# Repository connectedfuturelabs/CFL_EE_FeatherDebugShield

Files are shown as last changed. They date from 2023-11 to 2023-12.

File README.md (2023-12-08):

# Description
- This is a SWD breakout shield for the Feather M0 and a JTAG breakout shield for Feather ESP32.
- The Feather M0 has a provision for SWD debugging which requires soldering leads to the SWD pads on the bottom on the Feather M0. We made this shield so that we can debug a Feather M0 without having to solder leads. Instead, we use pogo pins to create the contact when the feather M0 is stacked on this shield.
- The Feather ESP32 can be debugged using the JTAG interface. This shield has a provision for debugging with ESP32 using solder bridges to create the necessary connections. **This configuration has not been tested.**
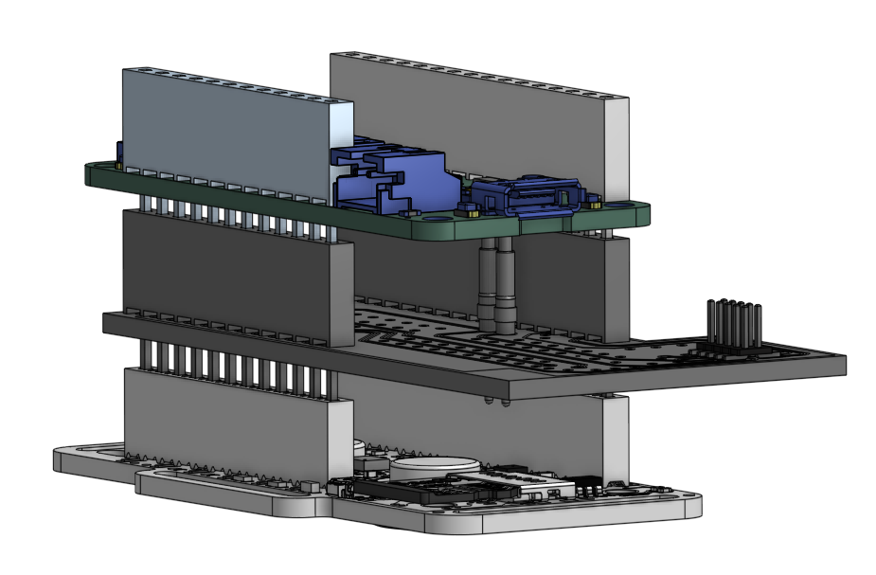
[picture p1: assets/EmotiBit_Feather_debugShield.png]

## Debug shield
**Note that this is a bare bones board (which is why the SM and silk screen are missing)**

| stage | how it looks |
|---|---|
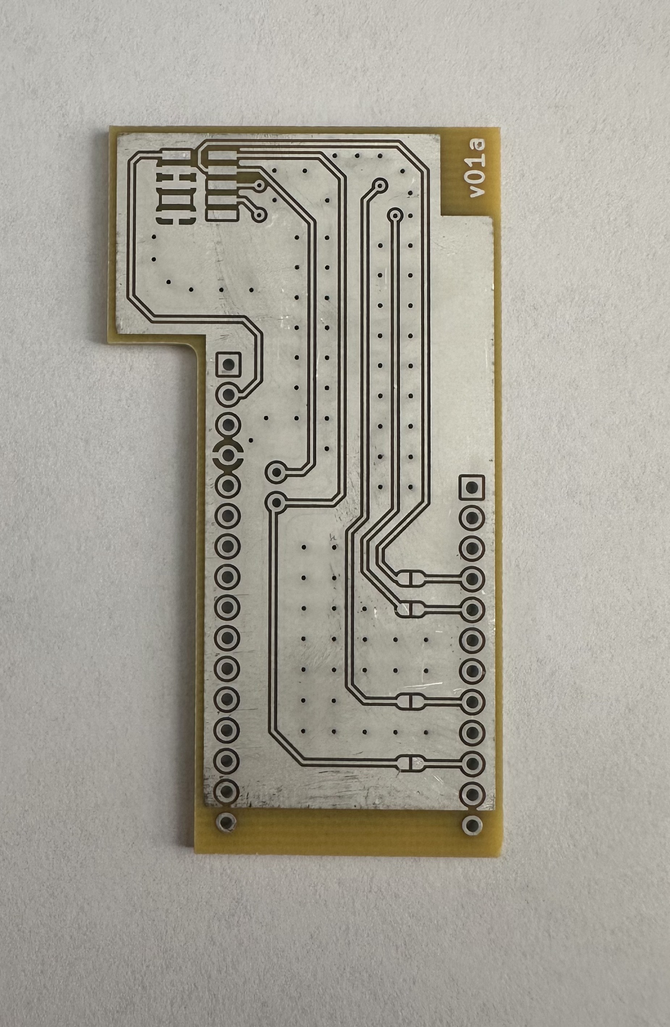
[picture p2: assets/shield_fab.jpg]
| After fabrication |  |
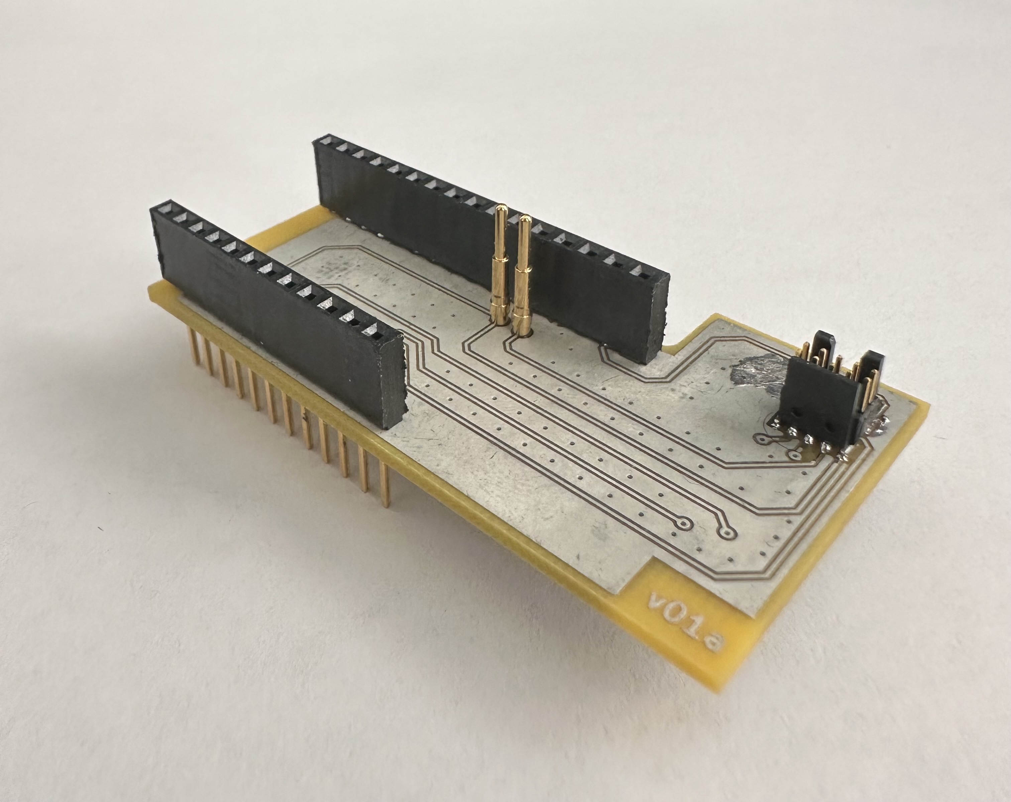
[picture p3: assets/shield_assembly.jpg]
| After Assembly |  |
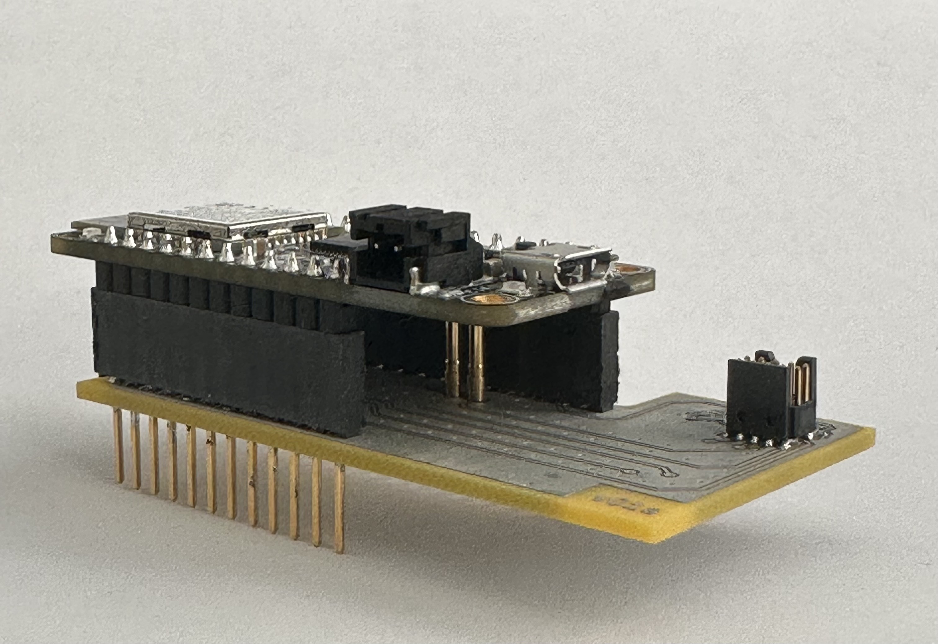
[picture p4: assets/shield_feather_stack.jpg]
| Stacked with a Feather |  |
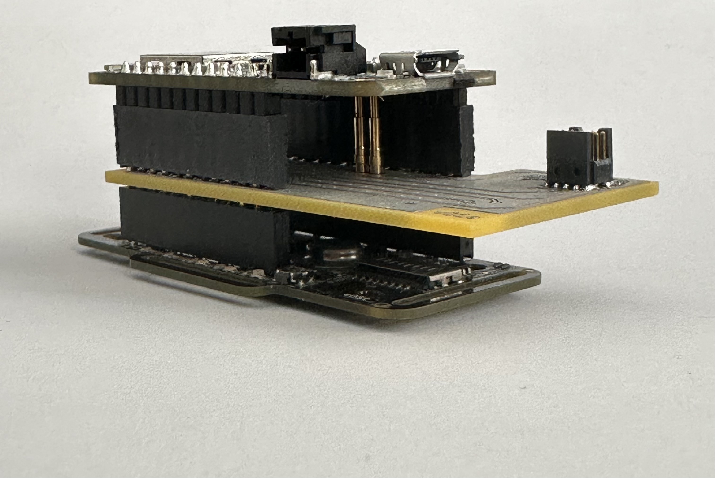
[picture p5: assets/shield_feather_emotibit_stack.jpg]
| Stacked with Feather and [EmotiBit](https://www.emotibit.com/) |  |

# Using this repository
- The latest release contains all files required for creating the board.
- To fabricate this board
  - Download the `.zip` from the release page.
  - The files needed for manufacturing are in the `Gerbers` folder.
  - Just upload the gerber design files on a manufacturer's website and choose other board specifications.
  - We used [`4PCB`](https://www.4pcb.com/pcb-prototype-2-4-layer-boards-specials.html) as our manufacturer.
  - The `_bom.csv` file contains the parts needed for assembly. You can directly upload the bom file into the digikey portal to get the required parts for assembly.
- Once the shield is fabbed and stacked, you can use the [10 pin JTAG conector cable](https://www.digikey.com/en/products/detail/olimex-ltd/ARM-JTAG-20-10/3471401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) to connecto to a [J-Link debugger](https://www.segger.com/products/debug-probes/j-link/).

## Assembly notes
- It is important to line up the pogo pins vertically to ensure there is a contact with the pads on the Feather. The following sequence helps with the allignment:
  - solder the 12 and 16 pin connector.
  - place the pogo pins in the correct position
  - stack the Feather on the shield.
  - then align the pogo pins with a pair of tweezers to ensure contact.
  - solder the pins in place
- We used stacking headers because we intend to use this as a triple stack with EmotiBit, but if you are only interested in debugging the Feather, then you can use normal female socket for the connector. 

# Additional Notes
- The design was created in Kicad 7.
- If you want to build on top of this design, please feel free to fork the repository and make the rewuired changes! you will need to download Kicad v7+ to work with the design files.

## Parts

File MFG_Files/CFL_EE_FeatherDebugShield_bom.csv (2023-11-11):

Component | Description | Part | References | Value | Footprint | Quantity Per PCB | Datasheet | Config | Land Pattern | MPN | Manufacturer | Max height | Mounting Type | Supplier 1 | Supplier 1 Link | Supplier 1 Part Number
1 | Generic connector, single row, 01x12, script generated (kicad-library-utils/schlib/autogen/connector/) | Conn_01x12 | J1 | Conn_01x12 | PinSocket_1x12_P2.54mm_Vertical | 1 | https://suddendocs.samtec.com/catalog_english/ssq_th.pdf |  | https://suddendocs.samtec.com/prints/ssq-1xx-xx-xx-x-xx-xxx-xx-xx.pdf | SSQ-112-03-G-S | Samtec Inc. | 8.61mm | Through hole | Digikey | https://www.digikey.com/en/products/detail/samtec-inc/SSQ-112-03-G-S/1111549 | SAM1198-12-ND
2 | Generic connector, single row, 01x16, script generated (kicad-library-utils/schlib/autogen/connector/) | Conn_01x16 | J2 | Conn_01x16 | PinSocket_1x16_P2.54mm_Vertical | 1 | https://suddendocs.samtec.com/catalog_english/ssq_th.pdf |  | https://suddendocs.samtec.com/prints/ssq-1xx-xx-xx-x-xx-xxx-xx-xx.pdf | SSQ-116-03-G-S | Samtec Inc. | 8.61mm | Through Hole | Digikey | https://www.digikey.com/en/products/detail/samtec-inc/SSQ-116-03-G-S/1111545 | SAM1198-16-ND
3 | Cortex Debug Connector, standard ARM Cortex-M SWD and JTAG interface | Conn_ARM_JTAG_SWD_10 | J4 | Conn_ARM_JTAG_SWD_10 | SAMTEC_FTSH-105-01-F-DV-K-TR | 1 | http://infocenter.arm.com/help/topic/com.arm.doc.ddi0314h/DDI0314H_coresight_components_trm.pdf |  | https://suddendocs.samtec.com/prints/ftsh-1xx-xx-xxx-dv-xxx-footprint.pdf | FTSH-105-01-F-DV-K-P | Samtec Inc. |  | SMD | Digikey | https://www.digikey.com/en/products/detail/samtec-inc./FTSH-105-01-F-DV-K-P/2649976 | SAM8797-ND
4 | CONTACT SPRING LOADED T/H GOLD | CONN_PROBE_SPRING_01X01_TH | J6 | SWCLK | CONN_PROBE_SPRING_01X01_C150H75 | 1 | https://www.mill-max.com/catalog/download/2020-03%3A025M.pdf |  | DNF | 0929-7-15-20-75-14-11-0 | Mill-Max Manufacturing Corp. | 12.2mm | Sureface Mount | DigiKey | https://www.digikey.com/en/products/detail/mill-max-manufacturing-corp/0929-7-15-20-75-14-11-0/5722643 | ED1420-ND
5 | CONTACT SPRING LOADED T/H GOLD | CONN_PROBE_SPRING_01X01_TH | J5 | SWDIO | CONN_PROBE_SPRING_01X01_C150H75 | 1 | https://www.mill-max.com/catalog/download/2020-03%3A025M.pdf |  | DNF | 0929-7-15-20-75-14-11-0 | Mill-Max Manufacturing Corp. | 12.2mm | Sureface Mount | DigiKey | https://www.digikey.com/en/products/detail/mill-max-manufacturing-corp/0929-7-15-20-75-14-11-0/5722643 | ED1420-ND
Component Groups: | 6
Component Count: | 9
Fitted Components: | 5
Number of PCBs: | 1
Total components: | 5
Schematic Version: | v01a
Schematic Date: | 2023-10-23
PCB Variant: | default
BoM Date: | 10/23/2023 11:08:31 AM
Schematic Source: | CFL_FeatherDebugShield.kicad_sch
KiCad Version: | Eeschema 7.0.6

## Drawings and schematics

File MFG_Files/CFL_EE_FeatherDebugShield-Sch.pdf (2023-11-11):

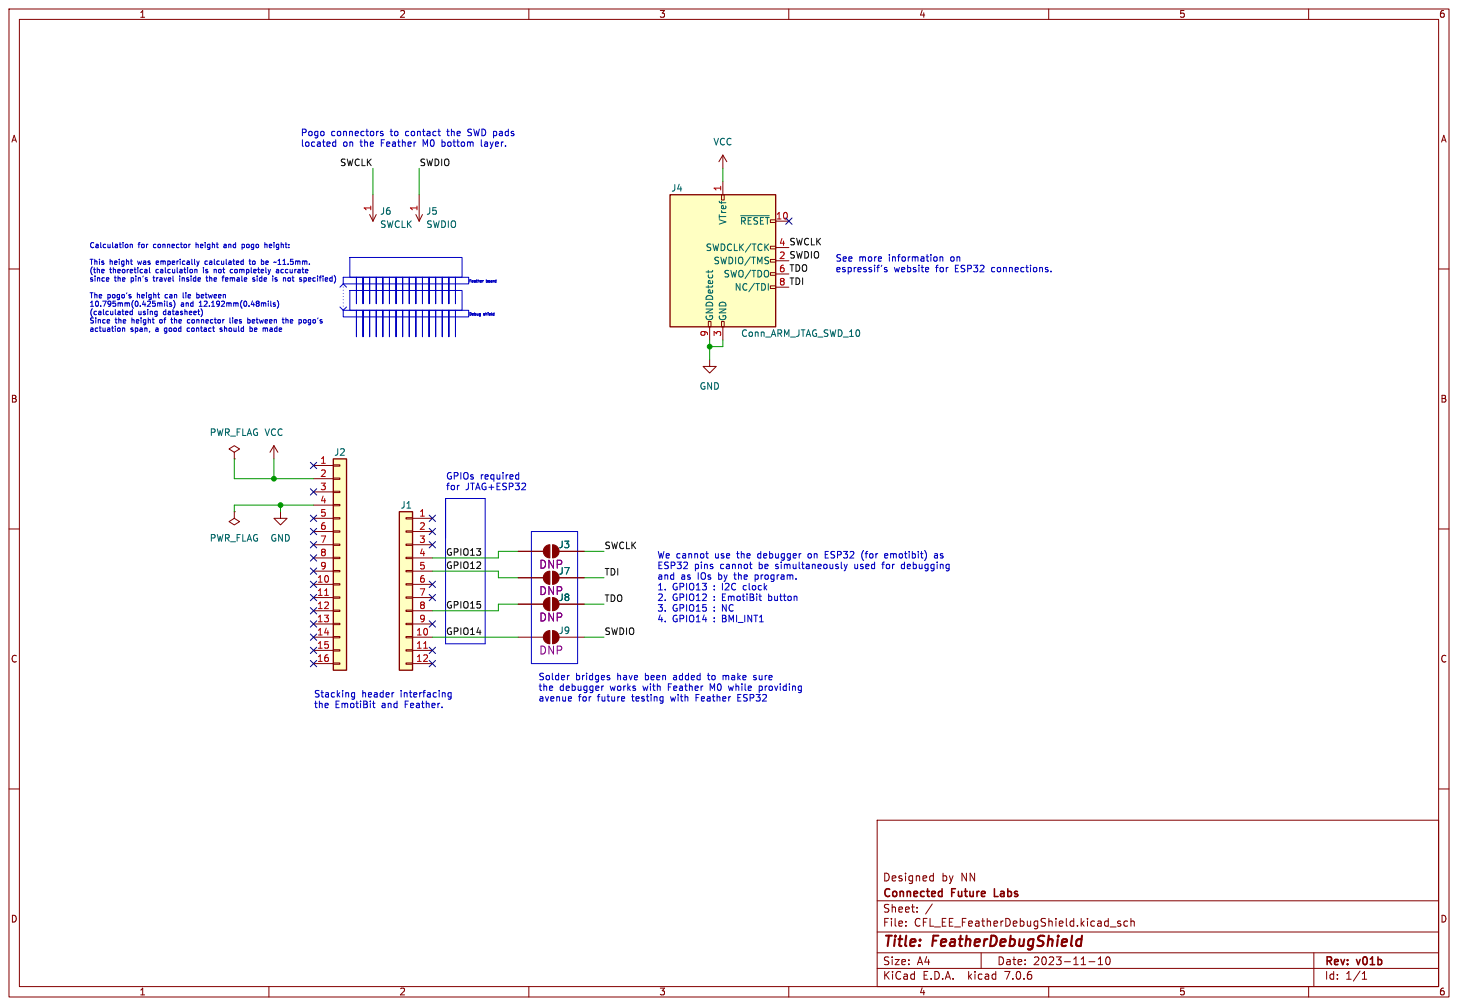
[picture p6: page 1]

3 SWDCLK/TCK 4 SWO/TDO 6 NC/TDI 8 GNDDetect 9

since the pin's travel inside the female side is not specified) The pogo's height can lie between

the debugger works with Feather M0 while providing
avenue for future testing with Feather ESP32

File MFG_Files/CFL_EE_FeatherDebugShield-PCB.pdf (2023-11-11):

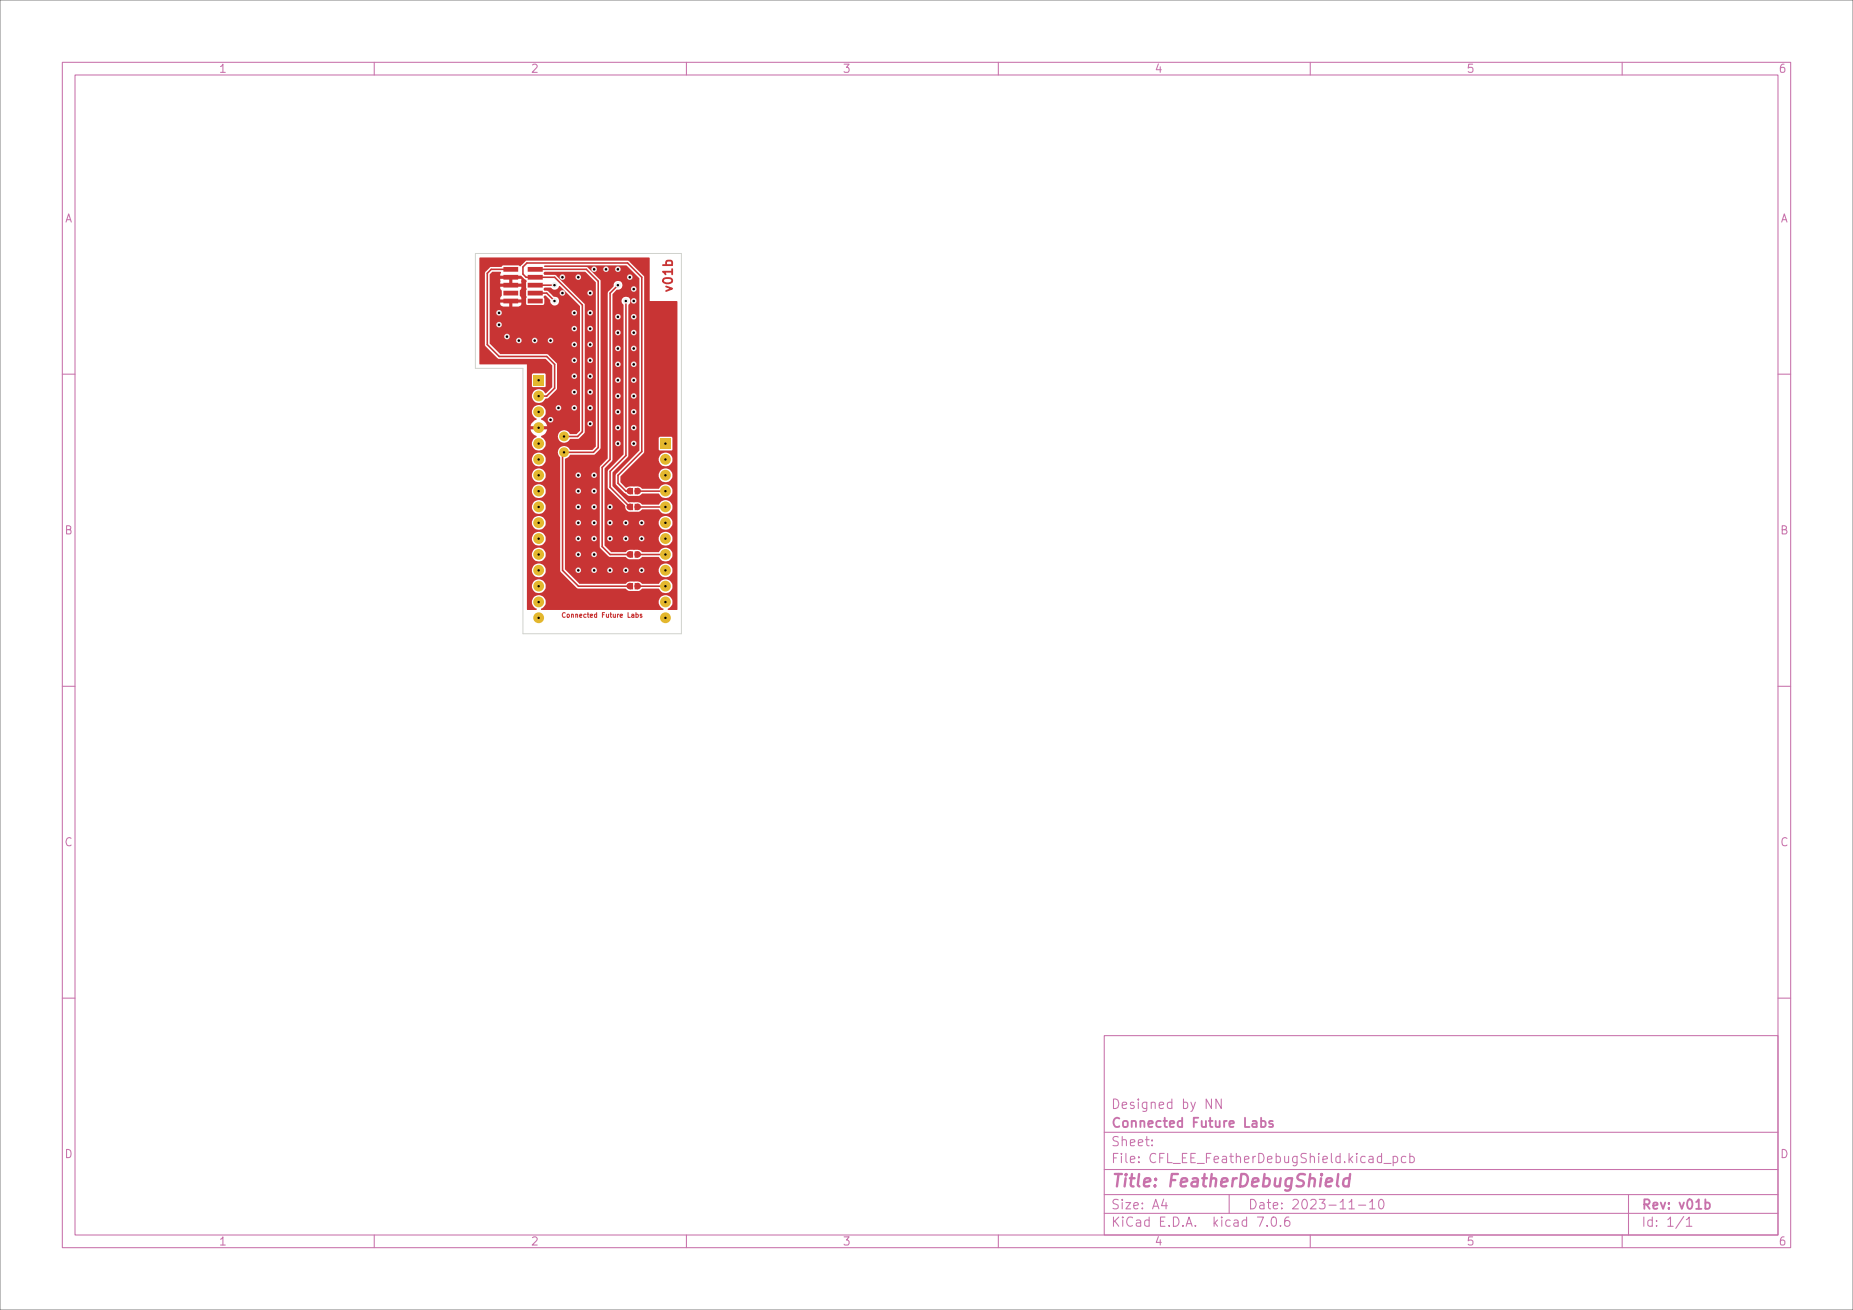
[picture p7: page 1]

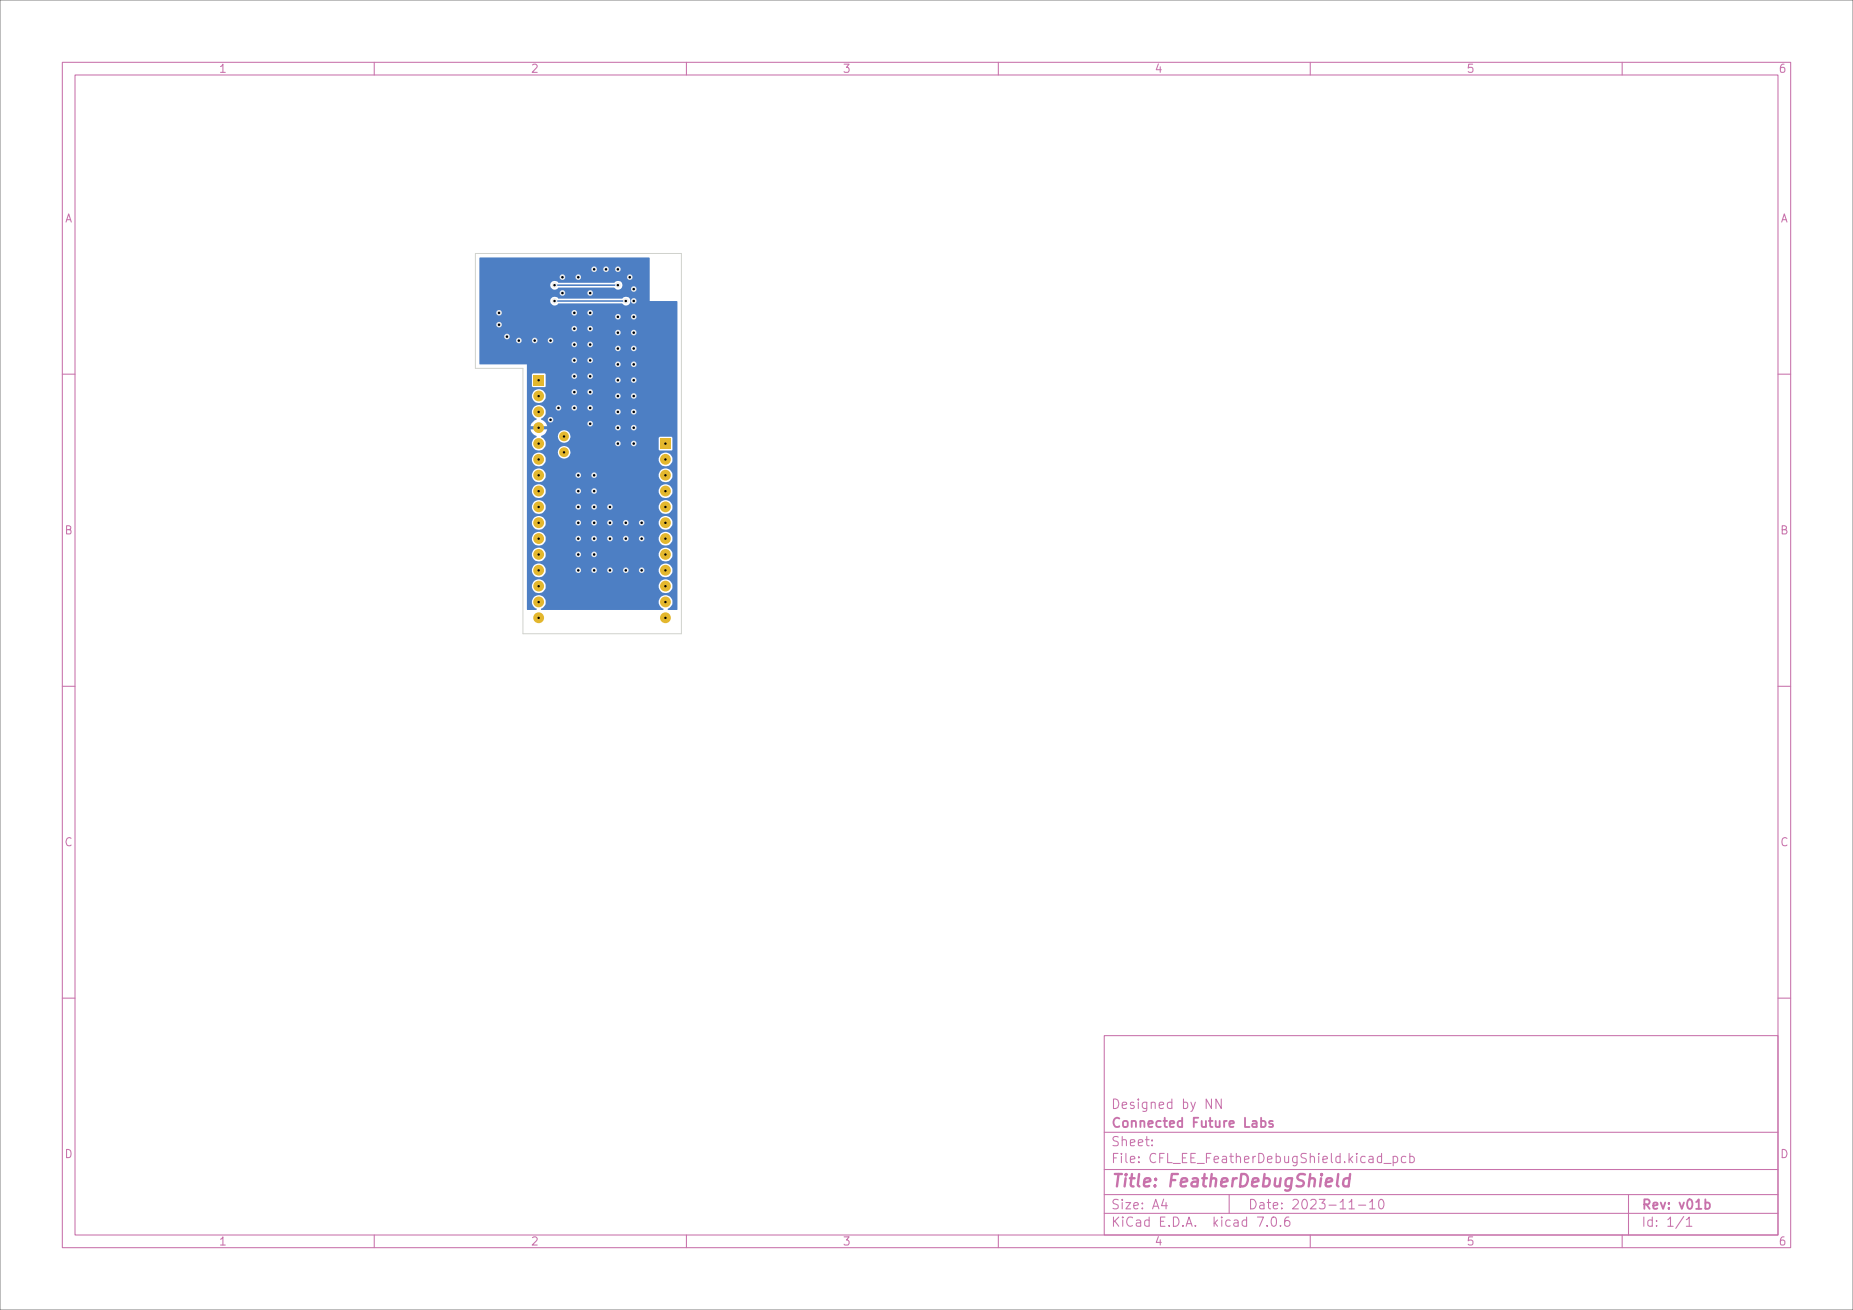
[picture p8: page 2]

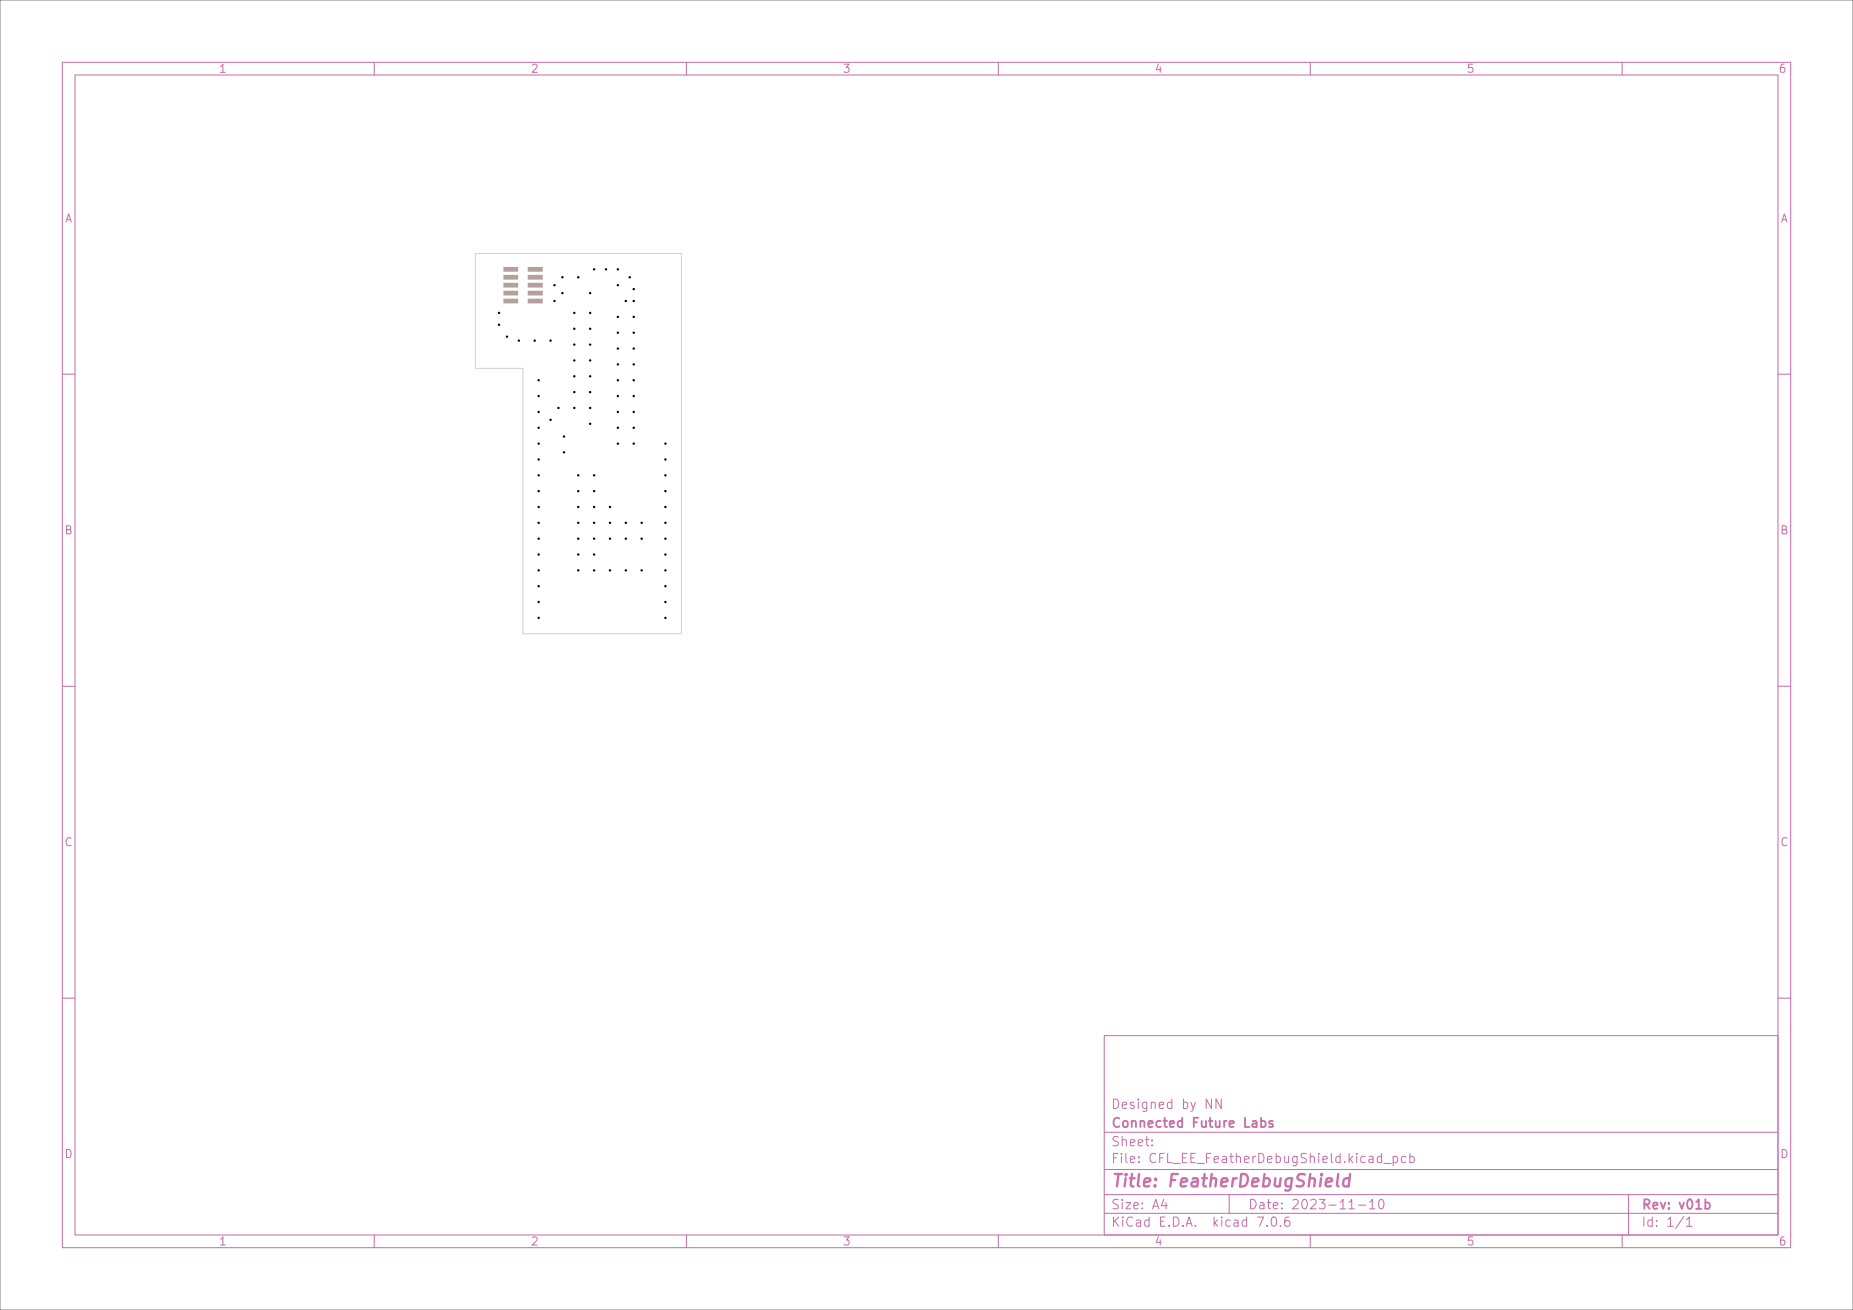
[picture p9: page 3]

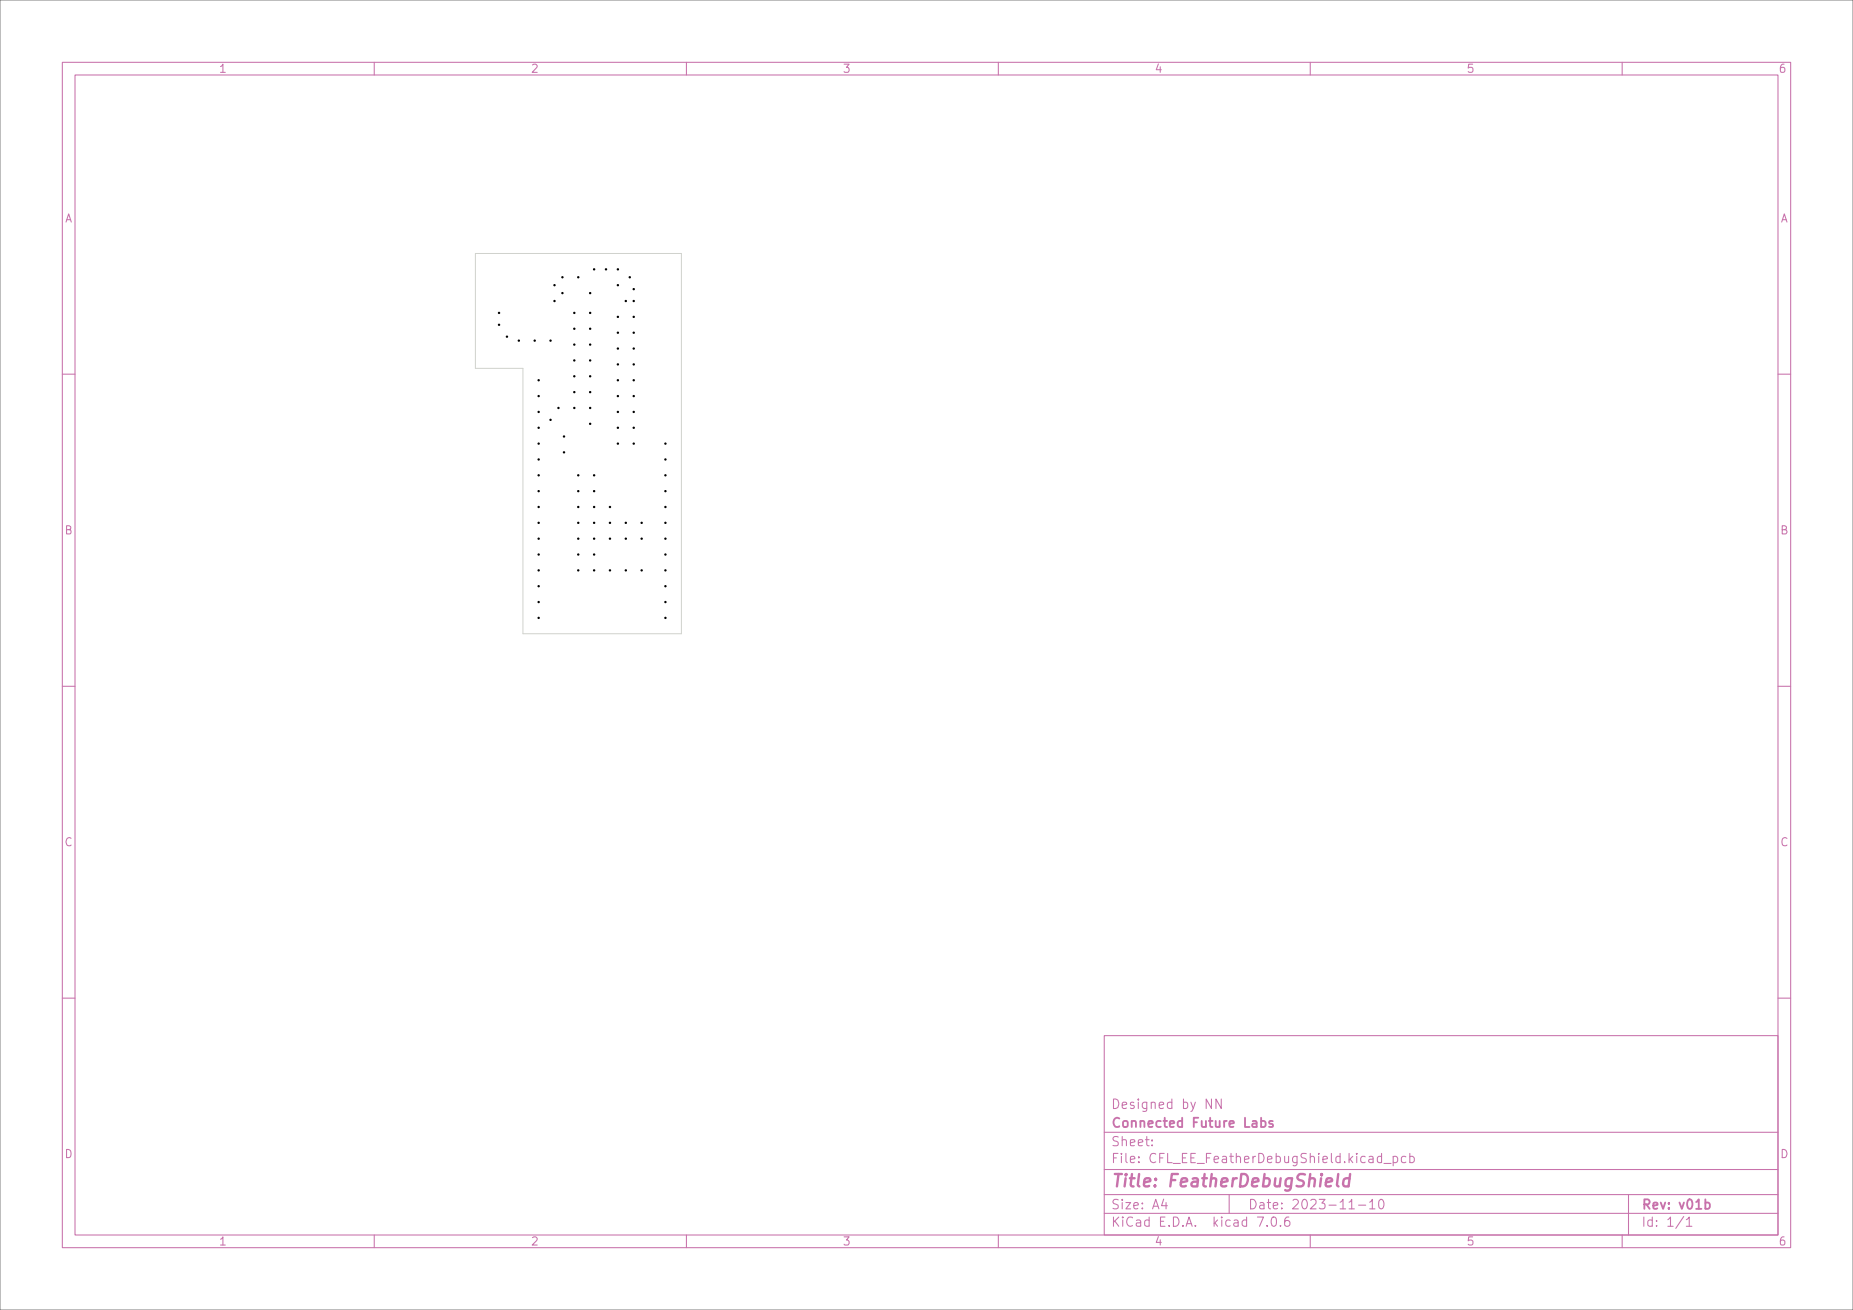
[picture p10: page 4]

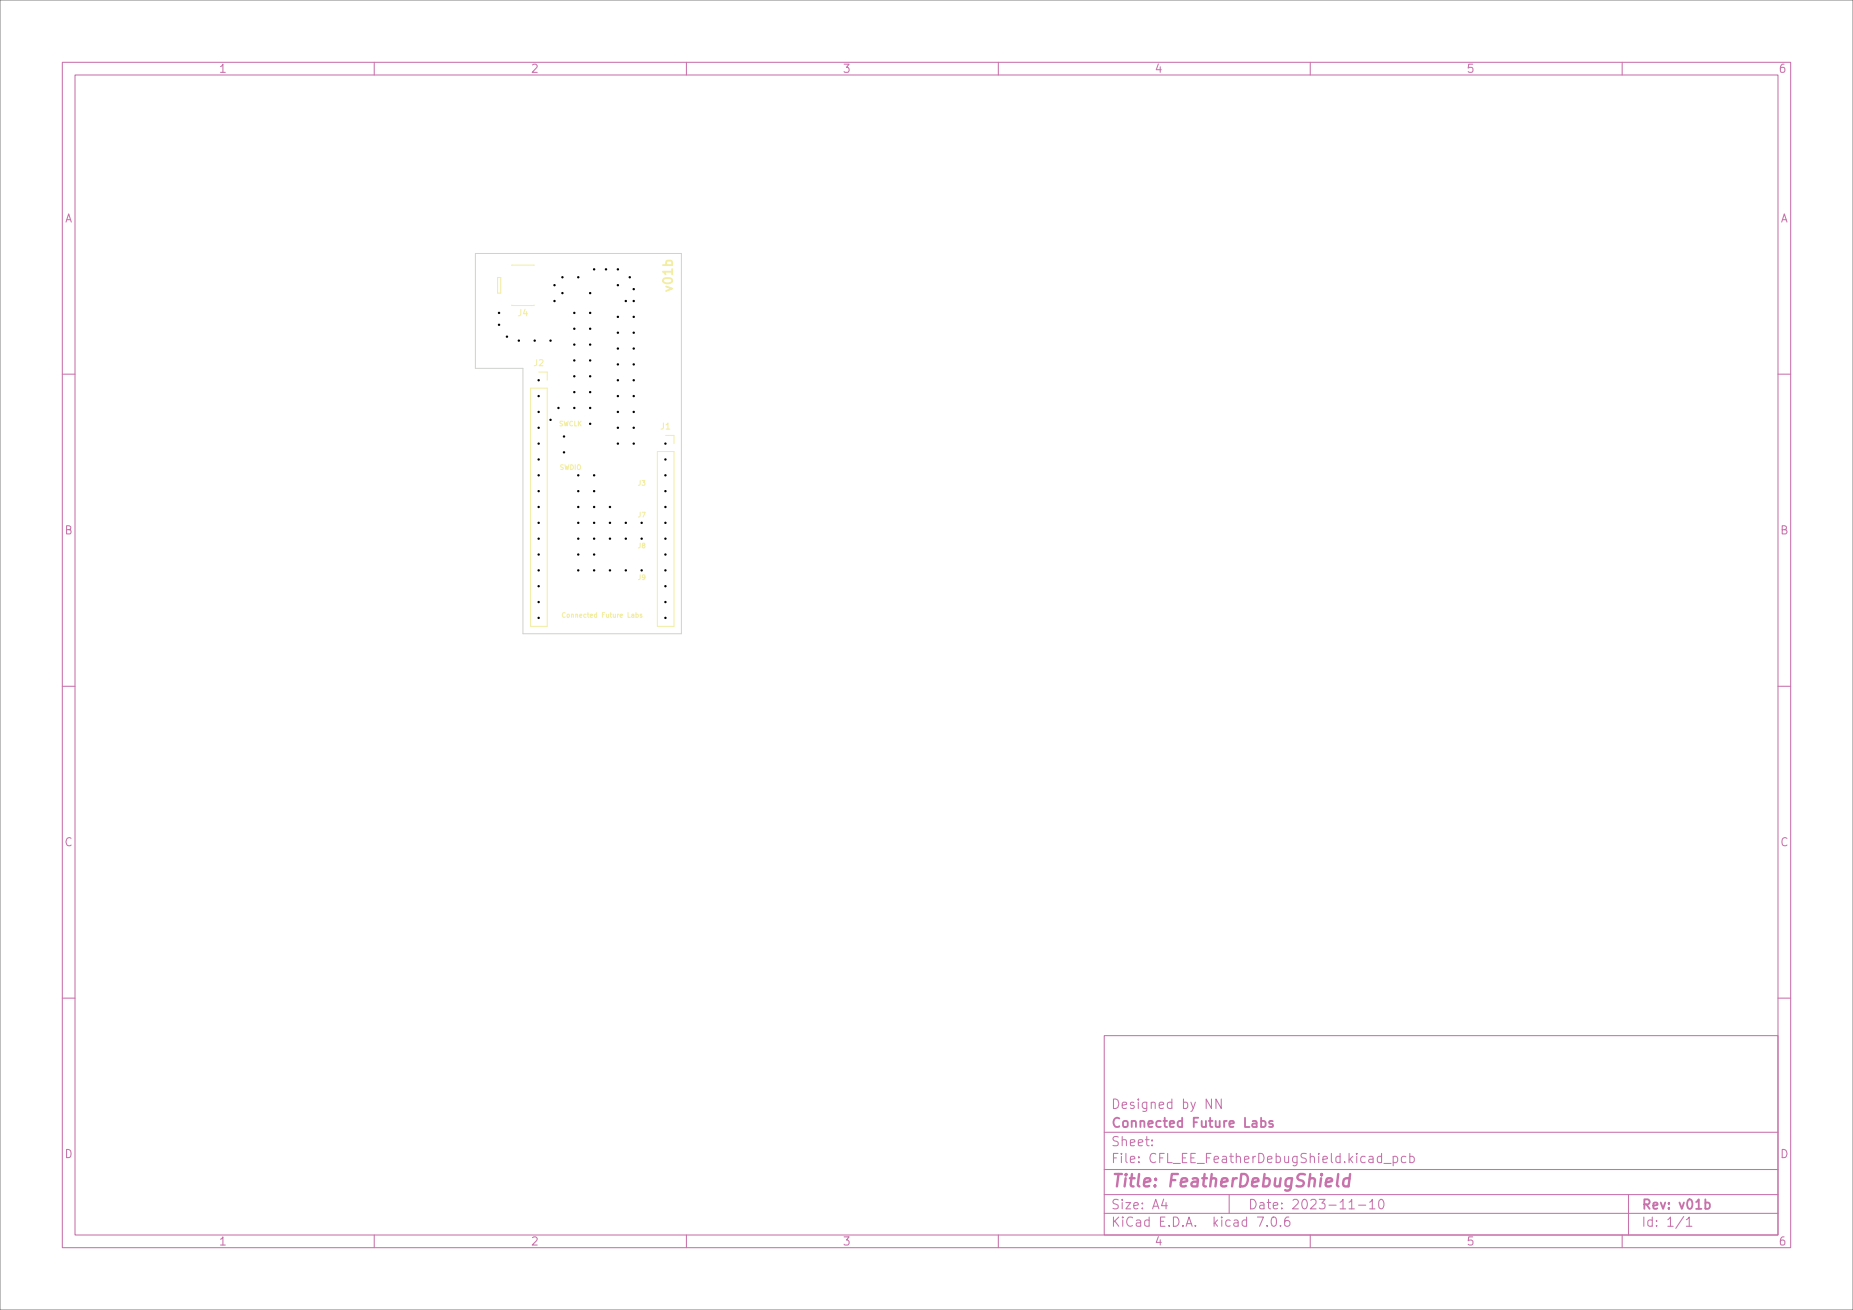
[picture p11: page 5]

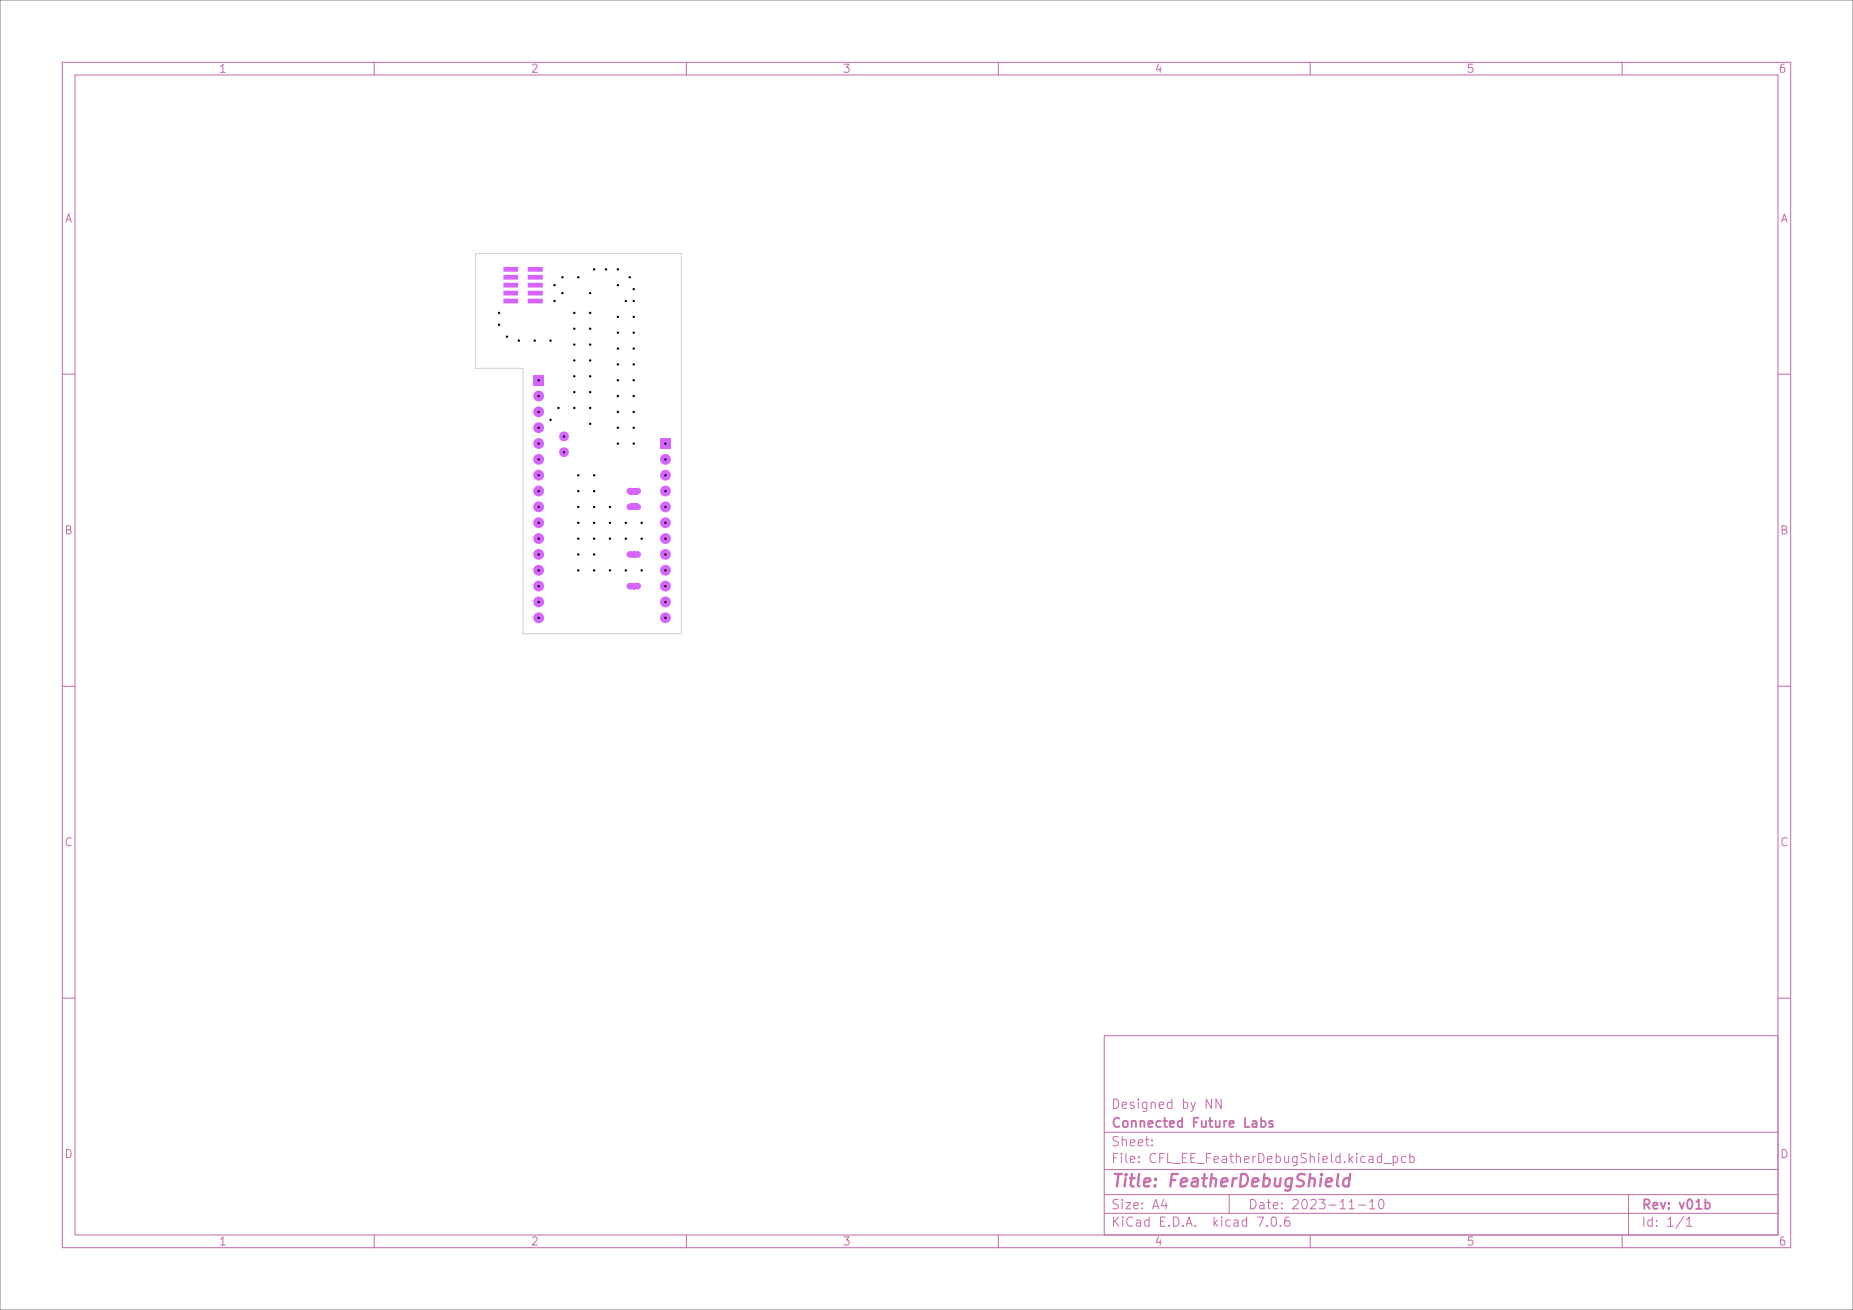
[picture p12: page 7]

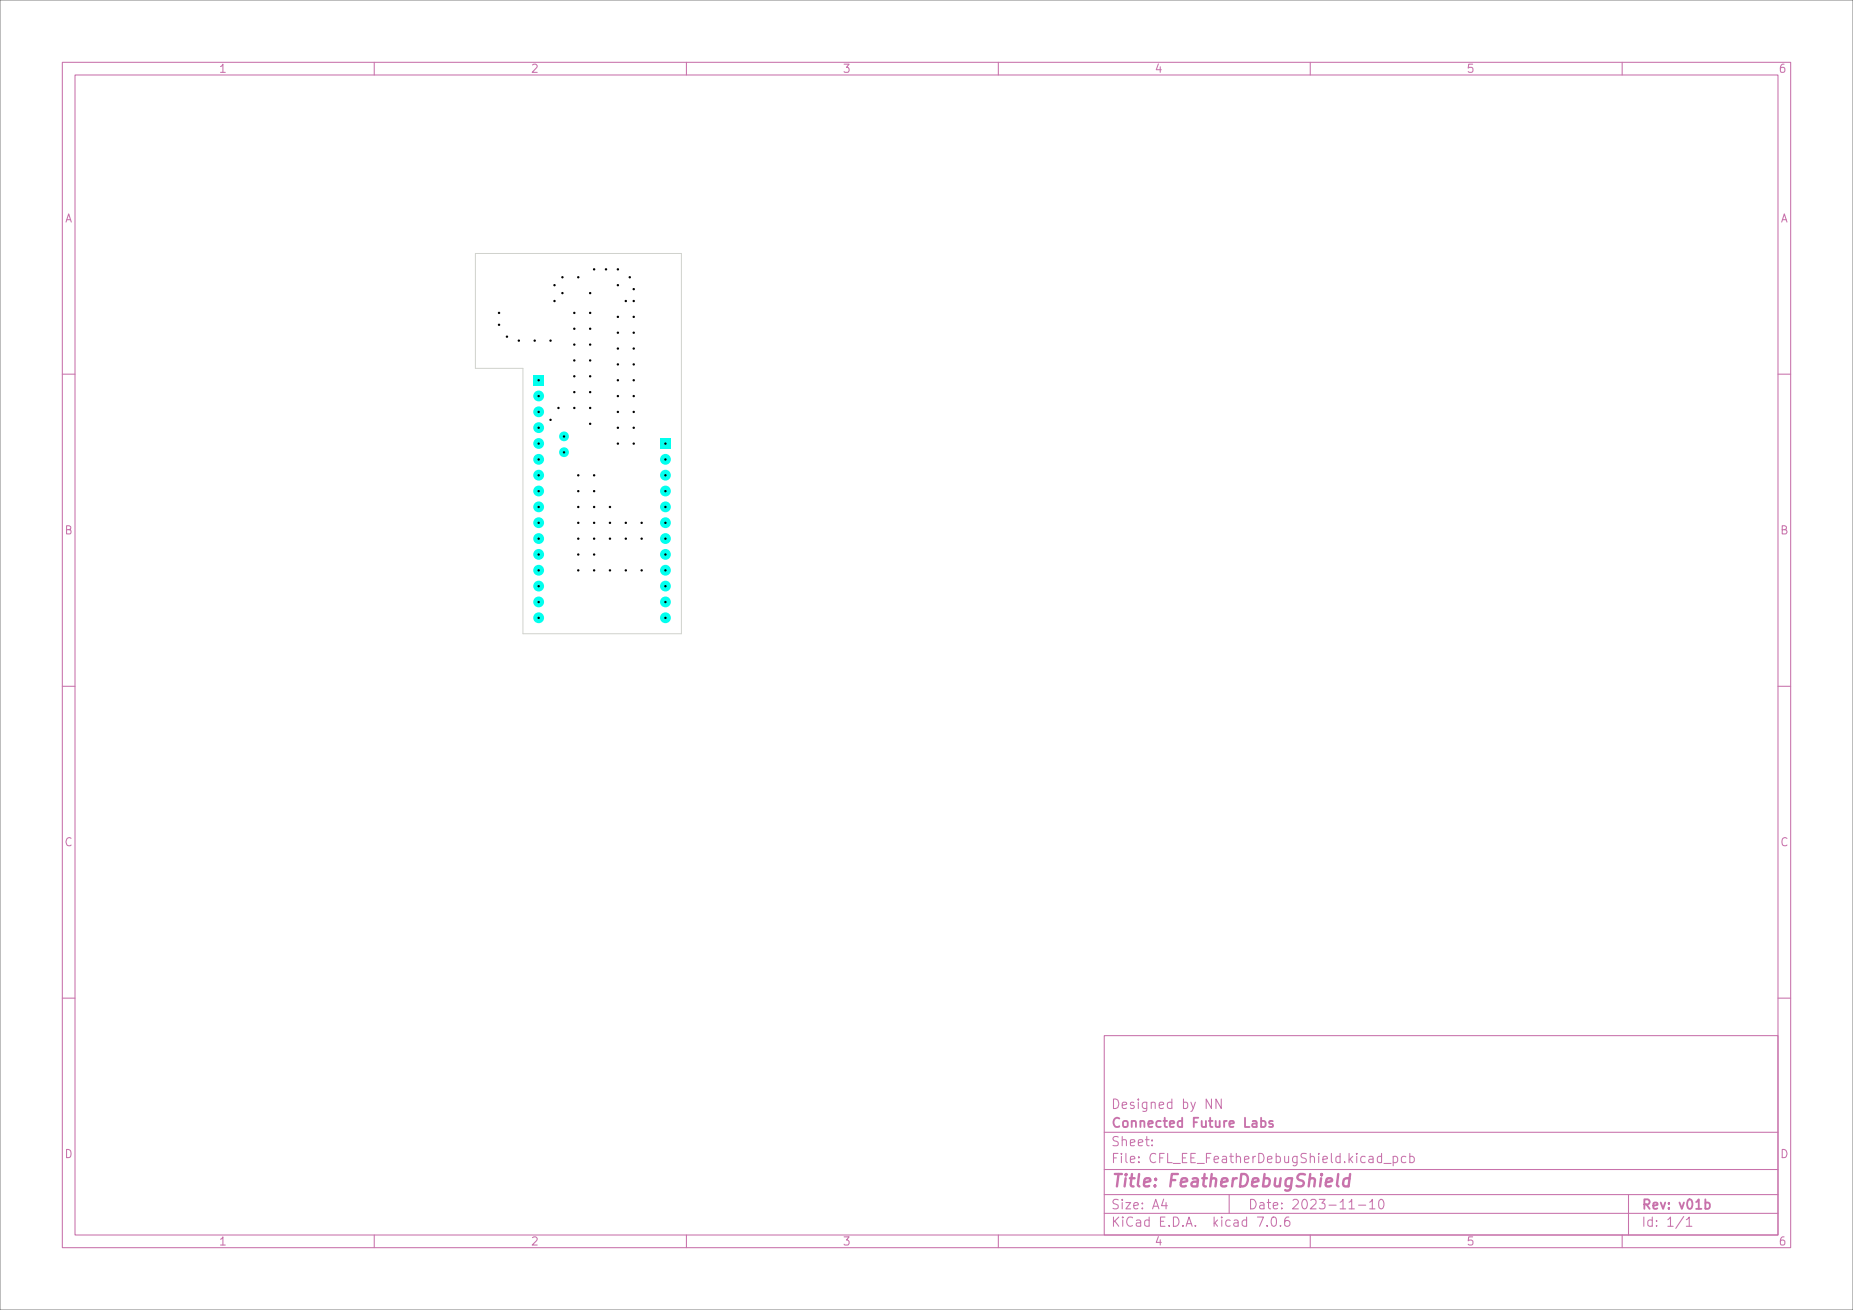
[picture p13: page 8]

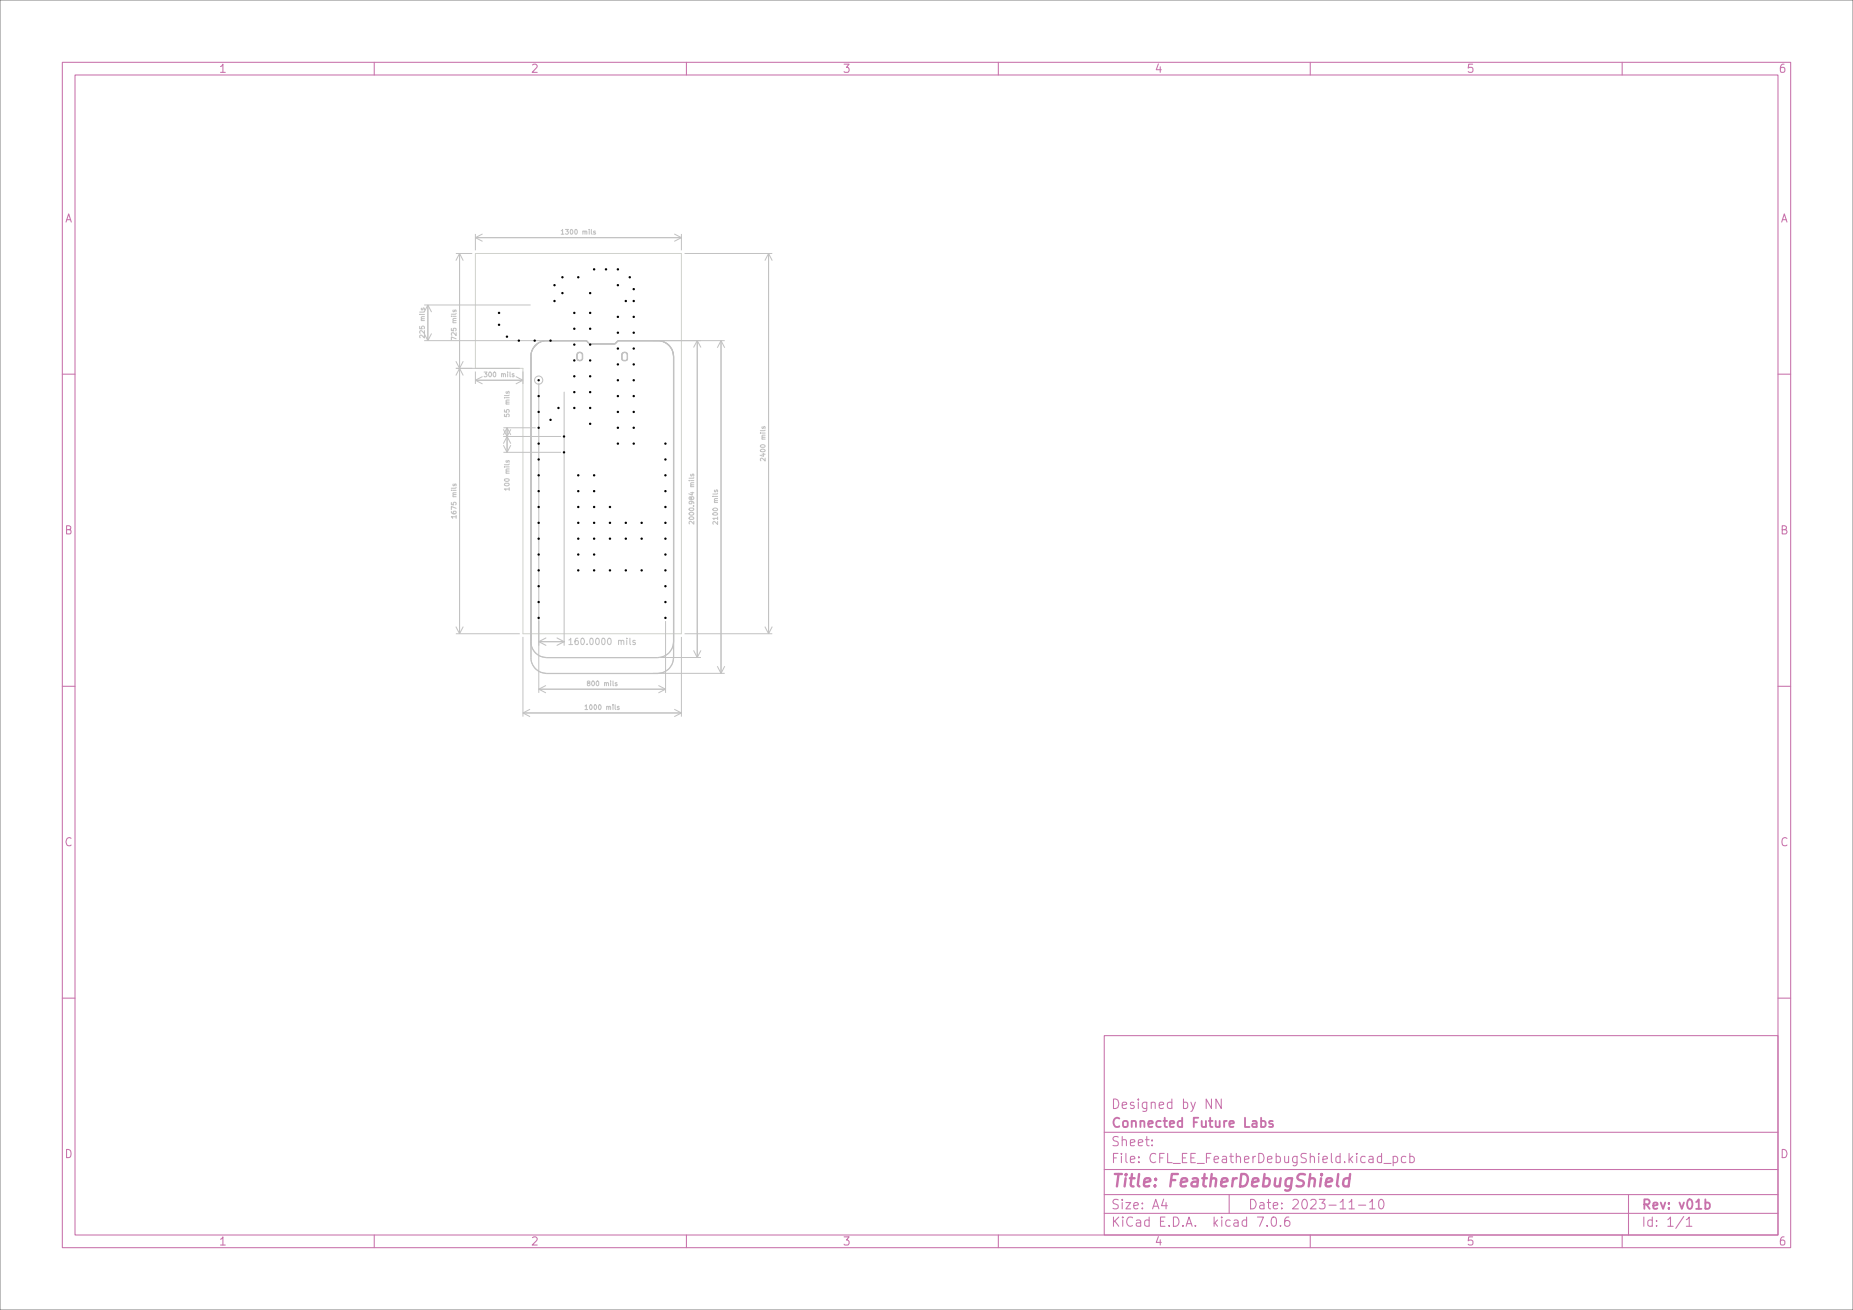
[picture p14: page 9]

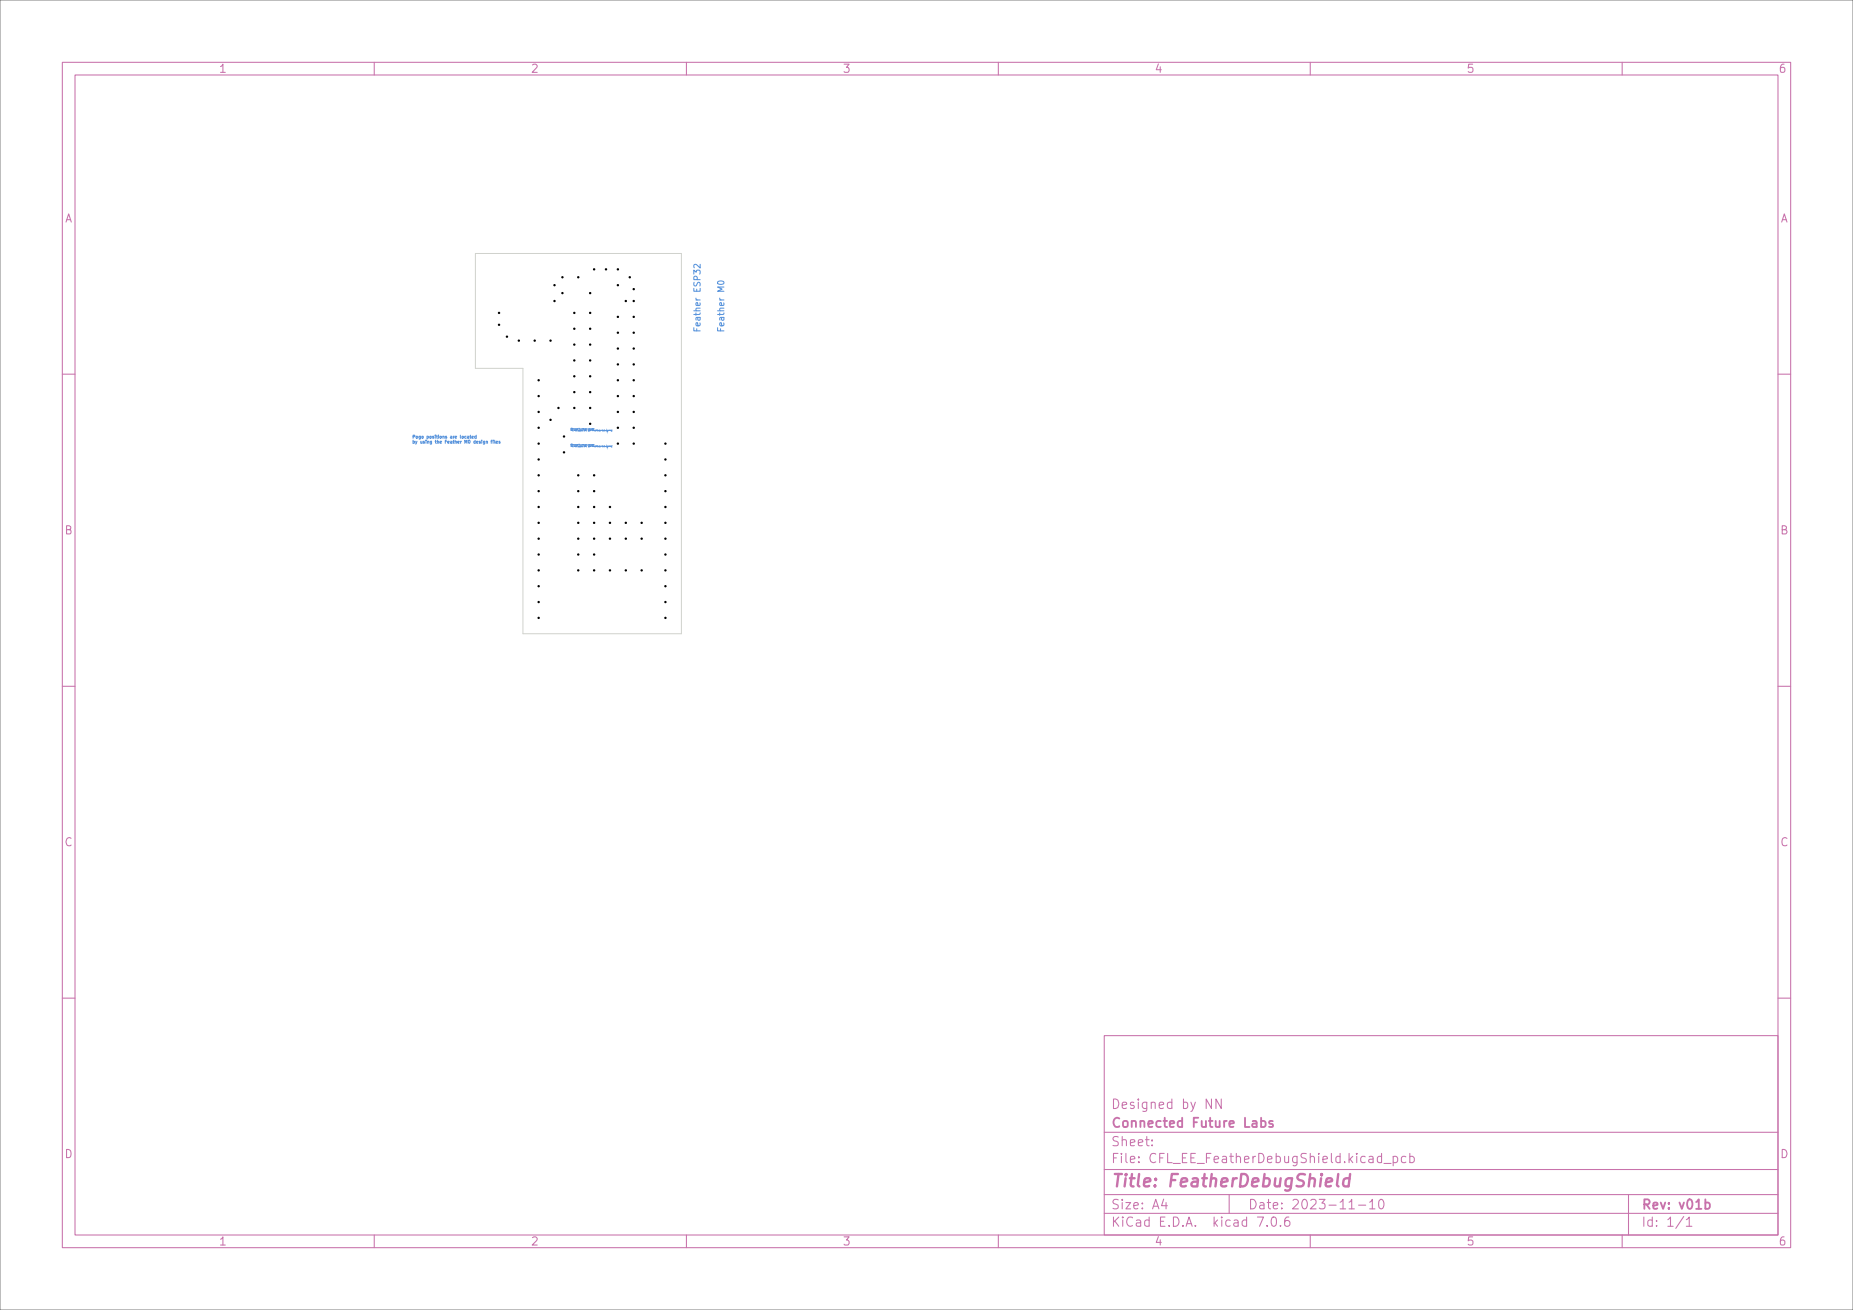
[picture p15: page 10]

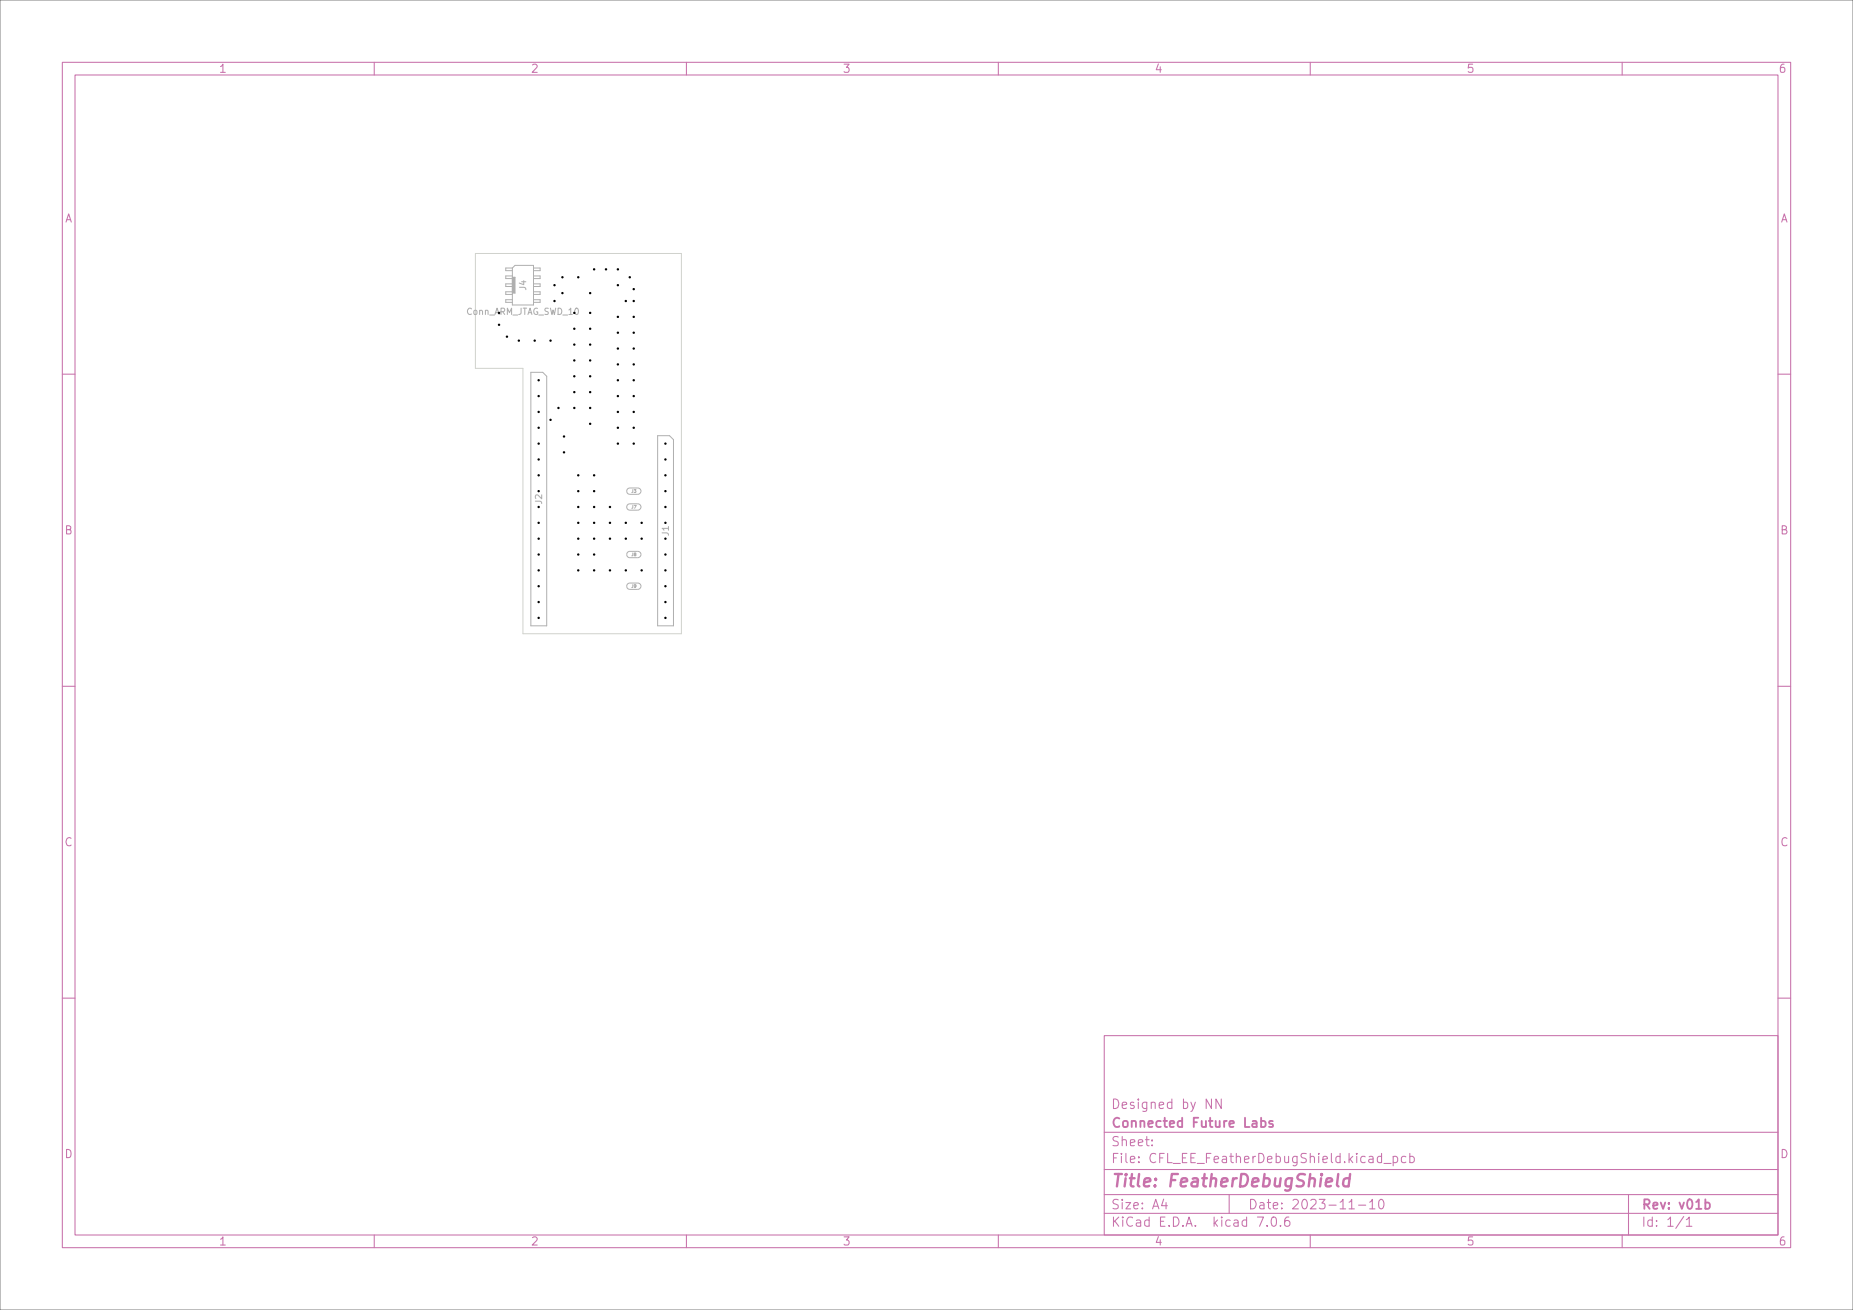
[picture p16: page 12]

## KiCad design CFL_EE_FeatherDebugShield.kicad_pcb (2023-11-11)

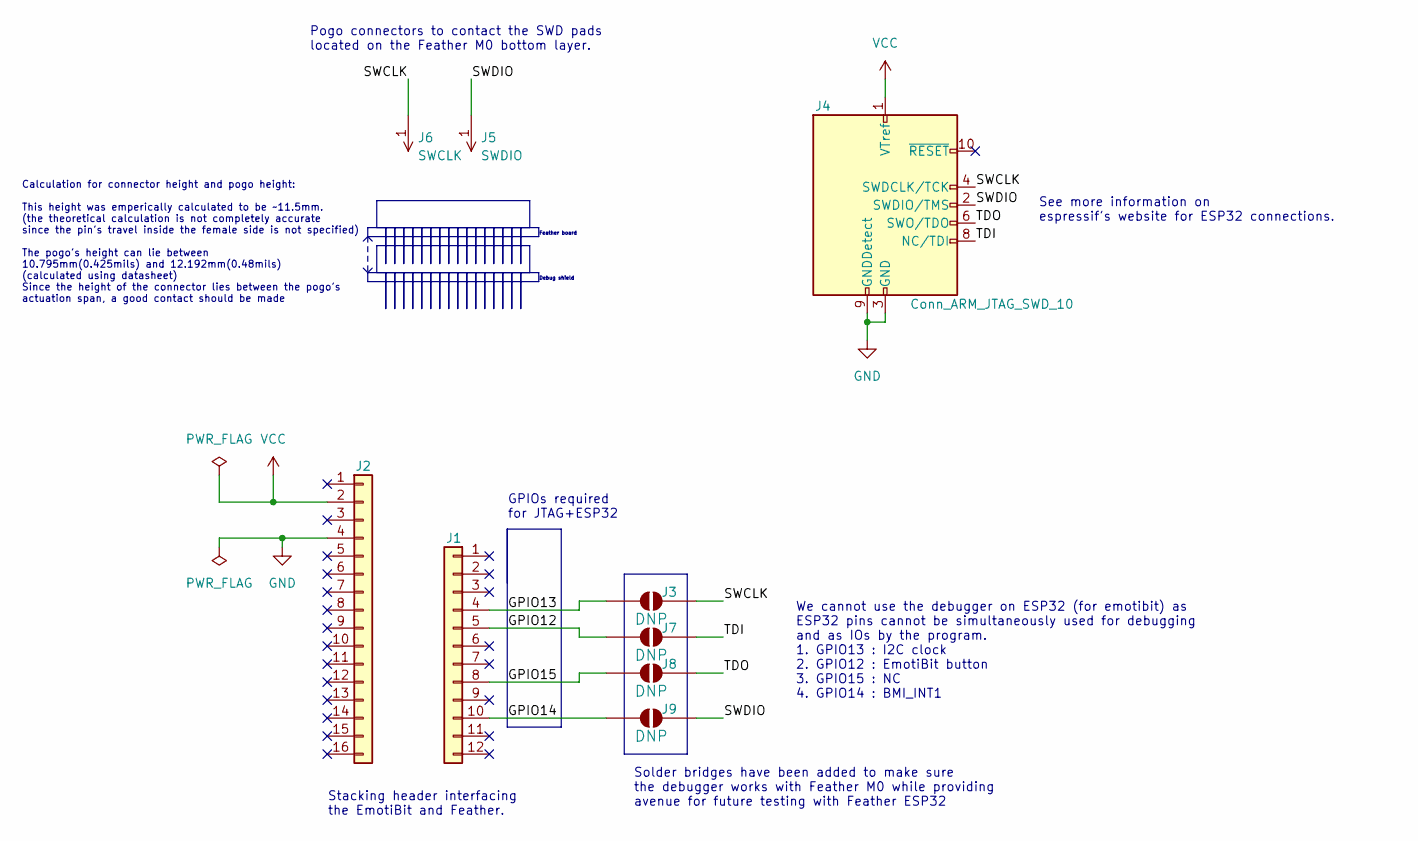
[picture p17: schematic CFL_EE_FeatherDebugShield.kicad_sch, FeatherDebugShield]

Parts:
J1: Conn_01x12; PinSocket_1x12_P2.54mm_Vertical; MPN SSQ-112-03-G-S
J2: Conn_01x16; PinSocket_1x16_P2.54mm_Vertical; MPN SSQ-116-03-G-S
J3, J7, J8, J9: CONN_JUMPER_NO; CONN_SLDR_BRDG_NO
J4: Conn_ARM_JTAG_SWD_10; SAMTEC_FTSH-105-01-F-DV-K-TR; MPN FTSH-105-01-F-DV-K-P
J5: SWDIO; CONN_PROBE_SPRING_01X01_C150H75; MPN 0929-7-15-20-75-14-11-0
J6: SWCLK; CONN_PROBE_SPRING_01X01_C150H75; MPN 0929-7-15-20-75-14-11-0

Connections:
/GPIO12: J1.5, J7.1
/GPIO13: J1.4, J3.1
/GPIO14: J1.10, J9.1
/GPIO15: J1.8, J8.1
/SWCLK: J3.2, J4.4 (SWDCLK/TCK), J6.1
/SWDIO: J4.2 (SWDIO/TMS), J5.1, J9.2
/TDI: J4.8 (NC/TDI), J7.2
/TDO: J4.6 (SWO/TDO), J8.2
GND: J2.4, J4.3 (GND), J4.5 (GND), J4.9 (GNDDetect)
VCC: J2.2, J4.1 (VTref)

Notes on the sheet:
Stacking header interfacing the EmotiBit and Feather.
Debug shield
See more information on espressif's website for ESP32 connections.
Pogo connectors to contact the SWD pads located on the Feather M0 bottom layer.
We cannot use the debugger on ESP32 (for emotibit) as ESP32 pins cannot be simultaneously used for debugging and as IOs by the program. 1. GPIO13 : I2C clock 2. GPIO12 : EmotiBit button 3. GPIO15 : NC 4. GPIO14 : BMI_INT1
Feather board
GPIOs required for JTAG+ESP32
Calculation for connector height and pogo height: This height was emperically calculated to be ~11.5mm. (the theoretical calculation is not completely accurate since the pin's travel inside the female side is not specified) The pogo's height can lie between 10.795mm(0.425mils) and 12.192mm(0.48mils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
Solder bridges have been added to make sure the debugger works with Feather M0 while providing avenue for future testing with Feather ESP32

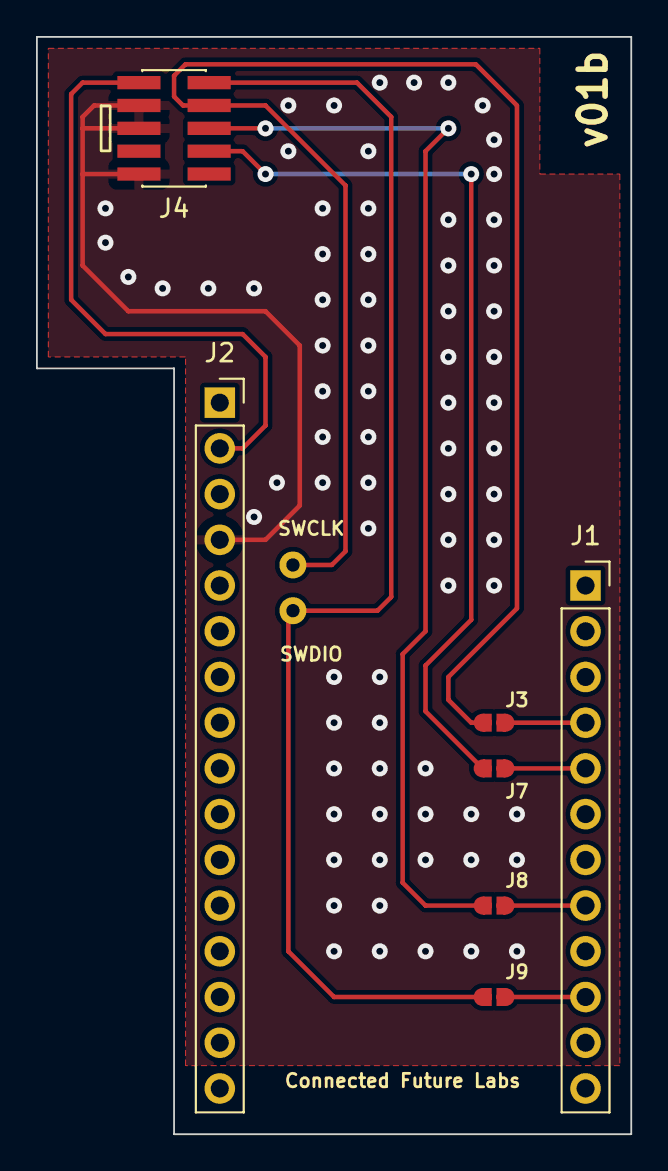
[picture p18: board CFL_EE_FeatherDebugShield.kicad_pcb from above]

Board: 2 copper layers, 33.0 x 61.0 mm, 9 parts (0 on the bottom side), 10 nets.

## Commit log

2023-10-23 adding v01a files
    [CFL_EE_FeatherDebugShield-B_Cu.gbl, CFL_EE_FeatherDebugShield-B_Mask.gbs, CFL_EE_FeatherDebugShield-B_Silkscreen.gbo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]
2023-11-11 minor mods sch and pcb. version bump to v01b
    [CFL_EE_FeatherDebugShield.kicad_pcb, CFL_EE_FeatherDebugShield.kicad_sch]
2023-11-11 adding MFG files
    [CFL_EE_FeatherDebugShield-B_Cu.gbl, CFL_EE_FeatherDebugShield-B_Mask.gbs, CFL_EE_FeatherDebugShield-B_Silkscreen.gbo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]
2023-11-11 adding bom file
    [CFL_EE_FeatherDebugShield_bom.csv]
2023-12-08 Adding stl for 3d seembly
